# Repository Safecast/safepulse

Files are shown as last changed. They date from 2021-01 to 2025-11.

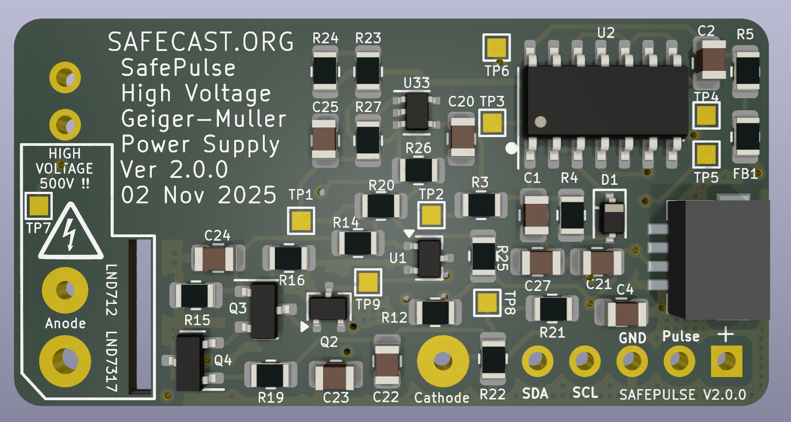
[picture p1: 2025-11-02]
SafePulse_back.jpg

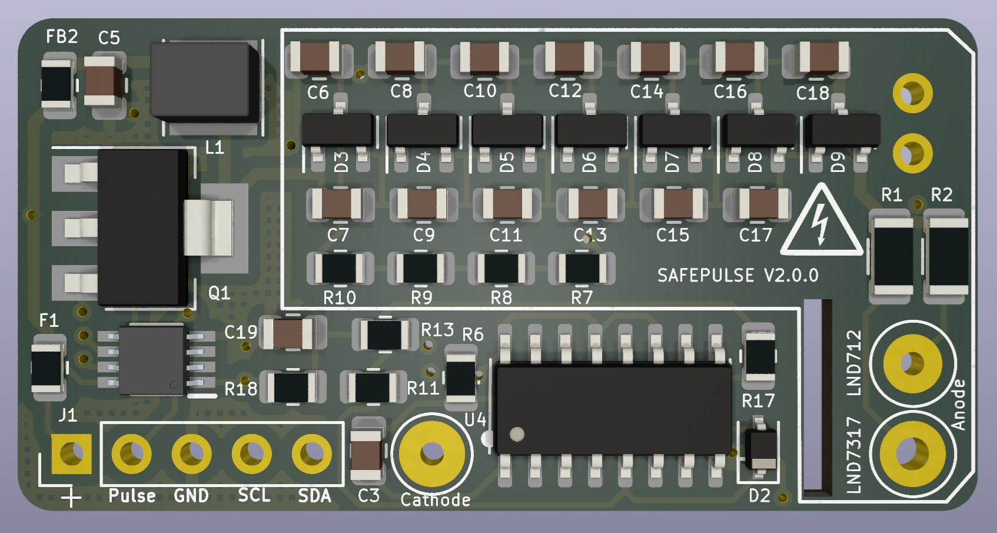
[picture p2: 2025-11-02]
SafePulse_front.jpg

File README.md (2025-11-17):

# SafePulse

An open-source high-voltage power supply (HVPS) and pulse counter designed for Geiger tubes. The Safepulse is utilized in the newest version of Safecast devices, the [bGeigieZen](https://bgeigiezen.safecast.jp) and can be bough directly at [https://bgeigiezen.safecast.jp/store-2/safepulse/](https://bgeigiezen.safecast.jp/store-2/safepulse/)

Safepulse V1 2 5
---

## Table of Contents

- [Overview](#overview)
- [History](#history)
- [Features](#features)
- [Getting Started](#getting-started)
  - [Prerequisites](#prerequisites)
  - [Installation](#installation)
- [Documentation](#documentation)
- [Contributing](#contributing)
- [Issues and Support](#issues-and-support)
- [License](#license)

---

## Overview

SafePulse is a project aimed at creating a fully open-source high-voltage power supply that is compact, efficient, and reliable. Designed specifically for Geiger counters, it facilitates accurate radiation detection and measurement.

---

## History

The SafePulse journey began with Safecast's need for a high-performance HVPS that exceeded existing market solutions. Dan Sythe of International Medcom played a pivotal role in guiding the development process, providing components like the iRover—a commercial-grade miniature HVPS recognized by the IAEA.

While the iRover set a benchmark for reliability and performance, SafePulse was developed to customize its needs to the varying requirements of numerous Safecast device types. Using an open-source design based on a HEX CMOS inverter oscillator, MOSFET switch, and Cockroft-Walton multiplier, the initial design achieved low power consumption (80 µA). However, challenges such as double pulses to the CPU and high count rate predictability led to refinements, including adding a multivibrator for fixed pulse widths. SafePulse is as much a reference design as a specific product, as variants of the core SafePulse design already feature a high-speed nano-amp I2C counter as well as alternative packagings.

SafePulse evolved into a compact 4-layer design to meet size constraints while ensuring consistent performance across component substitutions.

---

## Features

- **Open-Source Design**: All design files and source code are publicly available for modification.
- **High Performance**: Provides reliable high-voltage output tailored for Geiger tubes.
- **Compact and Efficient**: Space-saving design with minimal power consumption.

---

## Getting Started

### Prerequisites

To work with SafePulse, ensure you have the following tools and components:

- [KiCad](https://www.kicad.org/): Open-source electronic design automation software.
- Electronic components listed in the project's bill of materials (BOM).

### Installation

1. **Clone the Repository**:
```

git clone https://github.com/Safecast/safepulse.git

```

2. **Open with KiCad**:
- Launch KiCad.
- Open the `SafePulse.kicad_pro` project file from the cloned repository.

3. **Review and Modify**:
- Access schematics and PCB layouts.
- Make desired modifications or improvements.

---

## Documentation

Detailed schematics and design documents are available in the repository. Refer to the [SafePulse.pdf](https://github.com/Safecast/safepulse/blob/main/SafePulse.pdf) file for comprehensive information.

---

## Contributing

Contributions are welcome! Follow these steps:

1. Fork the repository.
2. Create a new branch for your feature or bug fix:
```

git checkout -b feature-name

```
3. Commit your changes:
```

git commit -m "Add feature"

```
4. Push to your forked repository:
```

git push origin feature-name

```
5. Submit a pull request detailing your changes.

Please ensure contributions align with project objectives and coding standards.

---

## Issues and Support

For issues or questions, visit the [GitHub Issues](https://github.com/Safecast/safepulse/issues) section of the repository.

---

## License

This project is licensed under the MIT License. You are free to use, modify, and distribute this software under its terms.
```

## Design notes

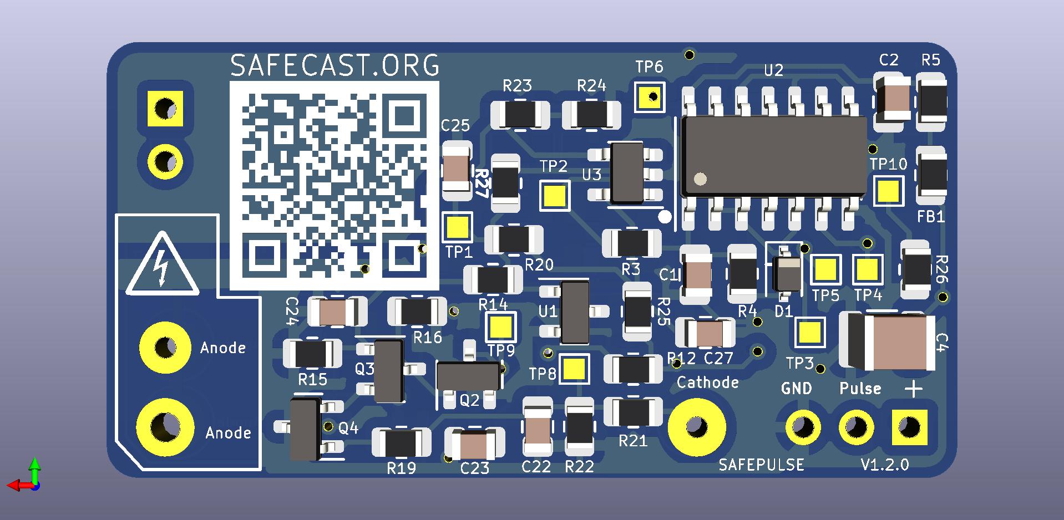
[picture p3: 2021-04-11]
Kicad files/OpenHVPS-5/OpenHVPS-5 front.jpg

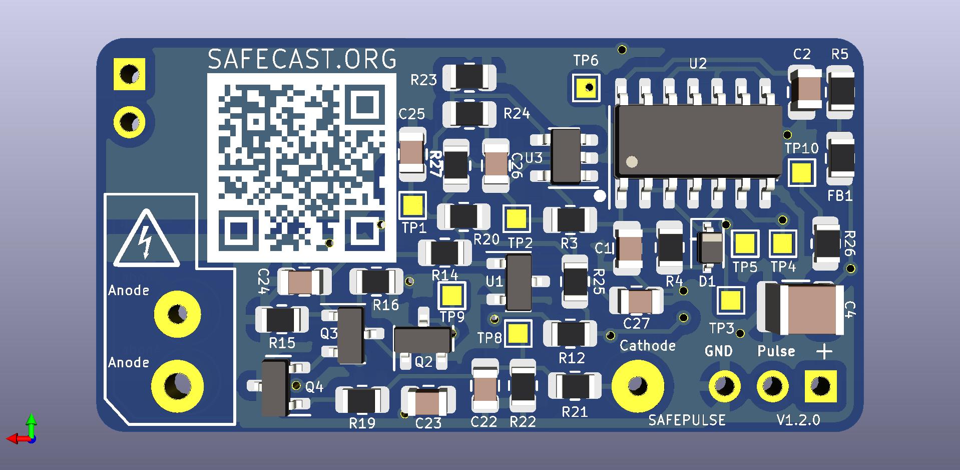
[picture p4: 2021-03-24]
Kicad files/OpenHVPS-5/OpenHVPS-5 font.jpg

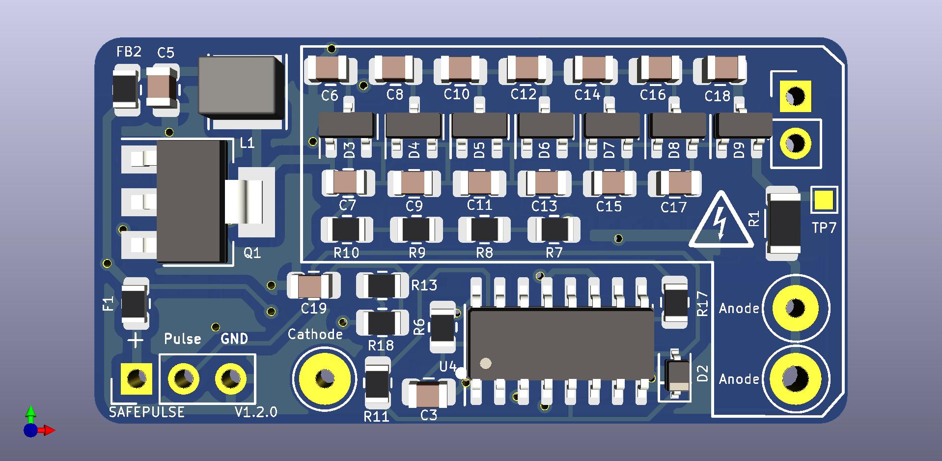
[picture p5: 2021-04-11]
Kicad files/OpenHVPS-5/OpenHVPS-5 back.jpg

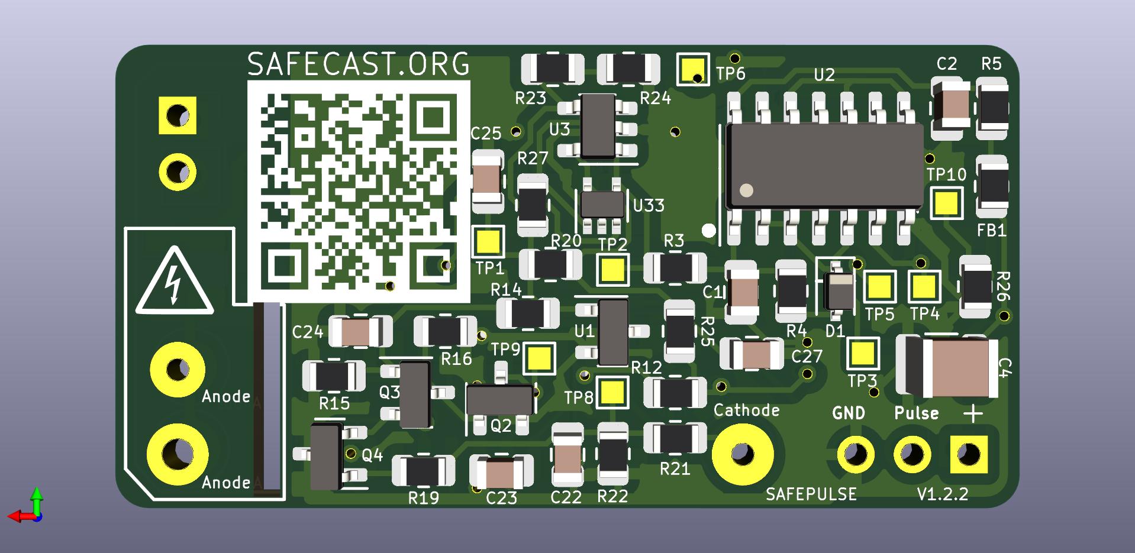
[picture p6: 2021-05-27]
Kicad files/OpenHVPS-5/SafePulse_front.jpg

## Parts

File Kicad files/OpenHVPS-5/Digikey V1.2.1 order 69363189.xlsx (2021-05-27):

# | QUANTITY | PART NUMBER | MANUFACTURER PART NUMBER | DESCRIPTION | CUSTOMER REFERENCE | BACKORDER | UNIT PRICE | EXTENDED PRICE
1 | 10 | 497-15222-1-ND | TS4061AILT-1.25 | IC VREF SHUNT 0.1% SOT23-3 | U1 | 0 | 97.9 | 979
2 | 10 | 296-26814-1-ND | TLV27L1IDBVT | IC OPAMP GP 1 CIRCUIT SOT23-5 | U3 | 10 | 178.7 | 1787
3 | 10 | MAX9910EXK+TCT-ND | MAX9910EXK+T | IC OPAMP GP 1 CIRCUIT SC70-5 | U33 | 0 | 122.6 | 1226
4 | 10 | RHM10.0MAICT-ND | KTR18EZPF1005 | RES SMD 10M OHM 1% 1/4W 1206 | R1 | 0 | 20.9 | 209
5 | 10 | 311-1.54MCRCT-ND | RC0805FR-071M54L | RES SMD 1.54M OHM 1% 1/8W 0805 | R27 | 0 | 5 | 50
6 | 10 | A129767CT-ND | CRGCQ0805F33K | CRGCQ 0805 33K 1% | R24 | 0 | 5.7 | 57
7 | 10 | 311-118KCRCT-ND | RC0805FR-07118KL | RES SMD 118K OHM 1% 1/8W 0805 | R20 | 0 | 5 | 50
8 | 5 | 40626-ND | 40626 | FUSE CLIP CARTRIDGE IN LINE |  | 0 | 27 | 135
9 | 6 | 399-15438-1-ND | C0805C111J5GAC7800 | CAP CER 110PF 50V NP0 0805 |  | 0 | 35 | 210
10 | 6 | 399-15439-1-ND | C0805C121J2GAC7800 | CAP CER 120PF 200V NP0 0805 |  | 0 | 41 | 246
11 | 6 | 399-15446-1-ND | C0805C131J5GAC7800 | CAP CER 130PF 50V NP0 0805 |  | 0 | 39 | 234
12 | 6 | 399-15456-1-ND | C0805C161J1GAC7800 | CAP CER 160PF 100V NP0 0805 |  | 0 | 45 | 270
13 | 6 | 399-16586-1-ND | C0805C181J5HACAUTO | CAP CER 0805 180PF 50V ULTRA STA |  | 0 | 19 | 114
14 | 6 | 490-10741-1-ND | GRM2165C1H201JA01D | CAP CER 200PF 50V C0G/NP0 0805 |  | 0 | 21 | 126
15 | 6 | RR12P20.0KDCT-ND | RR1220P-203-D | RES SMD 20K OHM 0.5% 1/10W 0805 |  | 0 | 12 | 72
16 | 6 | RHM21KAHCT-ND | KTR10EZPF2102 | RES SMD 21K OHM 1% 1/8W 0805 |  | 0 | 21 | 126
17 | 6 | 1712-CPF-A-0805B25KECT-ND | CPF-A-0805B25KE | RES SMD 25K OHM 0.1% 1/10W 0805 |  | 0 | 61 | 366
18 | 6 | P28.7KCCT-ND | ERJ-6ENF2872V | RES SMD 28.7K OHM 1% 1/8W 0805 |  | 0 | 12 | 72
19 | 6 | 541-RCS080530K0FKEACT-ND | RCS080530K0FKEA | RES SMD 30K OHM 1% 0.4W 0805 |  | 0 | 31 | 186
20 | 6 | P32.4KCCT-ND | ERJ-6ENF3242V | RES SMD 32.4K OHM 1% 1/8W 0805 |  | 0 | 12 | 72
21 | 6 | CR0805-FX-3322ELFCT-ND | CR0805-FX-3322ELF | RES SMD 33.2K OHM 1% 1/8W 0805 |  | 0 | 12 | 72
22 | 6 | 13-RT0805BRD0733K6LCT-ND | RT0805BRD0733K6L | RES 33.6K OHM 0.1% 1/8W 0805 |  | 0 | 43 | 258
23 | 6 | RHM34.8KAHCT-ND | KTR10EZPF3482 | RES SMD 34.8K OHM 1% 1/8W 0805 |  | 0 | 21 | 126
24 | 6 | RR12P35.7KDCT-ND | RR1220P-3572-D-M | RES SMD 35.7KOHM 0.5% 1/10W 0805 |  | 0 | 12 | 72
25 | 6 | P39.0KCCT-ND | ERJ-6ENF3902V | RES SMD 39K OHM 1% 1/8W 0805 |  | 0 | 12 | 72
26 | 10 | 1276-1014-1-ND | CL21C101JBANNNC | CAP CER 100PF 50V C0G/NP0 0805 |  | 0 | 6.3 | 63
27 | 10 | YAG3712CT-ND | AC0805FR-0722KL | RES SMD 22K OHM 1% 1/8W 0805 |  | 0 | 5.9 | 59
28 | 10 | 541-CRCW080524K0FKEACCT-ND | CRCW080524K0FKEAC | RES 24K OHM 1% 1/8W 0805 |  | 0 | 7.4 | 74
29 | 10 | 118-CR0805-FX-2702ELFCT-ND | CR0805-FX-2702ELF | RES SMD 27K OHM 1% 1/8W 0805 |  | 0 | 5.9 | 59
30 | 10 | RMCF0805FT28K0CT-ND | RMCF0805FT28K0 | RES 28K OHM 1% 1/8W 0805 |  | 0 | 3.2 | 32
31 | 10 | 2019-RK73H2ATTD2942FCT-ND | RK73H2ATTD2942F | RES 29.4K OHM 1% 1/4W 0805 |  | 0 | 4.1 | 41
32 | 10 | 541-30.9KCCT-ND | CRCW080530K9FKEA | RES SMD 30.9K OHM 1% 1/8W 0805 |  | 0 | 7.7 | 77
33 | 10 | 2019-RK73H2ATTD3162FCT-ND | RK73H2ATTD3162F | RES 31.6K OHM 1% 1/4W 0805 |  | 0 | 4.1 | 41
34 | 10 | RHM34KCHCT-ND | MCR10ERTF3402 | RES SMD 34K OHM 1% 1/8W 0805 |  | 0 | 2 | 20
35 | 10 | 541-36.0KCCT-ND | CRCW080536K0FKEA | RES SMD 36K OHM 1% 1/8W 0805 |  | 0 | 7.7 | 77
36 | 10 | 738-RMCF0805FT36K5CT-ND | RMCF0805FT36K5 | RES 36.5K OHM 1% 1/8W 0805 |  | 0 | 3.2 | 32
37 | 10 | 311-37.4KCRCT-ND | RC0805FR-0737K4L | RES SMD 37.4K OHM 1% 1/8W 0805 |  | 0 | 5 | 50
38 | 6 | 311-38.3KCRCT-ND | RC0805FR-0738K3L | RES SMD 38.3K OHM 1% 1/8W 0805 |  | 0 | 12 | 72
39 | 10 | RMCF0805FT39K2CT-ND | RMCF0805FT39K2 | RES 39.2K OHM 1% 1/8W 0805 |  | 0 | 3.2 | 32
40 | 10 | 541-CRCW080540K0FKEACT-ND | CRCW080540K0FKEA | RES SMD 40K OHM 1% 1/8W 0805 |  | 0 | 7.7 | 77

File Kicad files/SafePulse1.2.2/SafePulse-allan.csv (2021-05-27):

Item | Qty | Reference(s) | Value | LibPart | Digikey
1 | 1 | C1 | 150pF | Device:C | 732-12190-1-ND
2 | 5 | C2, C5, C19, C23, C27 | 10uF | Device:C | 1276-6455-1-ND
3 | 1 | C3 | 1nF | Device:C | 478-1371-1-ND
4 | 1 | C4 | 47uF | Device:C | 587-5425-1-ND
5 | 13 | C6, C7, C8, C9, C10, C11, C12, C13, C14, C15, C16, C17, C18 | 0.1uF | Device:C | 445-6808-1-ND
6 | 1 | C22 | 390pF | Device:C | 399-1132-1-ND
7 | 2 | C24, C25 | 10nF | Device:C | 1276-1015-1-ND
8 | 2 | D1, D2 | BAS16J | Diode:1N4148W | 1727-4797-1-ND
9 | 7 | D3, D4, D5, D6, D7, D8, D9 | BAV23S | Diode:BAV99 | BAV23SFSCT-ND
10 | 1 | F1 | Polyfuse | Device:Polyfuse_Small | 490-8510-1-ND
11 | 2 | FB1, FB2 | 74279220321 | Device:Ferrite_Bead | 732-6125-1-ND
15 | 1 | L1 | 4.7uH | 2021-01-06_02-33-04:NRS6020T2R2NMGJ | 587-4451-1-ND
16 | 1 | Q1 | FQT7N10L | Transistor_FET:IRF6655 | FQT7N10LTFCT-ND
17 | 1 | Q2 | BC846A | Transistor_BJT:BC846 | BC846A-7FDICT-ND
18 | 2 | Q3, Q4 | MMBT3906 | Transistor_BJT:MMBT3906 | MMBT3906LT1GOSCT-ND
19 | 1 | R1 | 4.99M | Device:R | RHM4.99MAICT-ND
20 | 1 | R3 | 100K | Device:R | RMCF0805FT100KCT-ND
21 | 1 | R4 | 10K | Device:R | RNCP0805FTD10K0CT-ND
22 | 3 | R5, R12, R25 | 100 | Device:R | A106053CT-ND
23 | 1 | R6 | 121k | Device:R | 2019-RK73H2ATTD1213FCT-ND
24 | 4 | R7, R8, R9, R10 | 22M | Device:R | RMCF0805FT22M0CT-ND
25 | 1 | R11 | 33k | Device:R | A129767CT-ND
26 | 2 | R13, R19 | 100k | Device:R | RMCF0805FT100KCT-ND
27 | 1 | R14 | 357k | Device:R | 2019-RK73H2ATTD3573FCT-ND
28 | 1 | R15 | 220k | Device:R | CR0805-FX-2203ELFCT-ND
29 | 1 | R16 | 1M | Device:R | YAG3361CT-ND
30 | 1 | R17 | 499k | Device:R | RMCF0805FT499KCT-ND
31 | 1 | R18 | 1k | Device:R | RNCP0805FTD1K00CT-ND
32 | 1 | R20 | 118K | Device:R | 311-118KCRCT-ND
33 | 1 | R21 | 47k | Device:R | 311-47.0KCRCT-ND
34 | 1 | R22 | 20k | Device:R | RMCF0805FT20K0CT-ND
35 | 2 | R23, R27 | 1.54M | Device:R | 311-1.54MCRCT-ND
36 | 1 | R24 | 22k | Device:R | CR0805-FX-2202ELFCT-ND
37 | 1 | R26 | 0.1E | Device:R | 408-1556-1-ND
40 | 1 | U2 | 74HC14 | 74xx:74HC14 | 296-9179-1-ND
41 | 1 | U3 | MAX9910EXK+T | Amplifier_Operational:MCP6L01Ux-xOT | MAX9910EXK+TCT-ND
42 | 1 | U4 | CD14538BM | 4xxx:4538 | 296-32849-5-ND
43 | 1 | Fuse Holder |  |  | 40626-ND

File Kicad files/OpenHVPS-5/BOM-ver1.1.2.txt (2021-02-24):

qty Digikey number

resistors
1  408-1556-1-ND
3  A106053CT-ND
1  YAG1240CT-ND
1  RNCP0805FTD10K0CT-ND
1  P20.0KCCT-ND
1  A129767CT-ND
1  311-47.0KCRCT-ND
2  RMCF0805FT100KCT-ND
1  2019-RK73H2ATTD1213FCT-ND
1  311-392KCRCT-ND
1  A126370CT-ND
1  RMCF0805FT499KCT-ND
1  YAG3361CT-ND
1  541-1.50MCCT-ND
1  311-3.16MCRCT-ND
1  RHM4.7MAICT-ND
5  RMCF0805FT22M0CT-ND

caps
1  732-12190-1-ND
1  1276-1261-1-ND
1  1276-1303-1-ND
2  478-1371-1-ND
1  1276-1015-1-ND
1  587-5425-1-ND
13 445-C2012X7T2E104K125AACT-ND
5  1276-6455-1-ND

semiconductors
2  1727-4797-1-ND
7  BAV23SFSCT-ND
1  BC846A-7FDICT-ND
2  MMBT3906LT1GOSCT-ND
1  FQT7N10LTFCT-ND
1  296-9179-1-ND
1  296-32849-5-ND
1  MAX4162EUK+TCT-ND
1  MAX6008AEUR+TCT-ND

Inductors
1  587-4451-1-ND
2  445-172907-1-ND

extra parts for 1.25V reference
1  MAX6006AEUR+TCT-ND
1   P357KDACT-ND
1  311-1.54MCRCT-ND

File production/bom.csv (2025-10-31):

Designator | Footprint | Quantity | Value | LCSC Part #
C1 | 0805 | 1 | 110pF | C17694684
C10, C11, C12, C13, C14, C15, C16, C17, C18, C21, C6, C7, C8, C9 | 0805 | 14 | 0.1uF | C710458
C19, C2, C23, C27, C5 | 0805 | 5 | 10uF | C1713
C20 | 0805 | 1 | 100pF | C62768
C22 | 0805 | 1 | 390pF | C1741
C24 | 0805 | 1 | 10nF | C97905
C25 | 0805 | 1 | 2.2uF | C19110
C3 | 0805 | 1 | 1nF | C94121
C4 | 0805 | 1 | 47uF | C76636
D1, D2 | D_SOD-323 | 2 | BAS16J | C282360
D3, D4, D5, D6, D7, D8, D9 | SOT-23 | 7 | BAV23S | C151049
F1 | 0805 | 1 | Polyfuse | C20978
FB1, FB2 | 0805 | 2 | 74279220321 | C515370
IC1 | SOP65P400X80-8N | 1 | S-35770E01I-K8T2U
J2 | 4208 | 1 | JST SM04B-SRSS-TB(LF)(SN) | C160404
L1 | L_Taiyo-Yuden_MD-4040 | 1 | 4.7uH | C5289366
Q1 | SOT-223-3_TabPin4 | 1 | FQT7N10L | C154506
Q2 | SOT-323_SC-70 | 1 | BC846A | C507907
Q3, Q4 | SOT-23 | 2 | MMBT3906 | C53444
R1 | 1206 | 1 | 4.99M | C488845
R10, R26, R7, R8, R9 | 0805 | 5 | 22M | C34719
R11 | 0805 | 1 | 33k | C17633
R12, R25, R5 | 0805 | 3 | 100 | C328380
R13, R19, R3 | 0805 | 3 | 100k | C96346
R14 | 0805 | 1 | 357k | C865422
R15 | 0805 | 1 | 220k | C104108
R16 | 0805 | 1 | 1M | C107700
R17 | 0805 | 1 | 499k | C17721
R18 | 0805 | 1 | 1k | C95781
R2 | 1206 | 1 | 10M | C275643
R20 | 0805 | 1 | 118K | C2999465
R21 | 0805 | 1 | 47k | C328397
R22 | 0805 | 1 | 20K | C2988970
R23, R27 | 0805 | 2 | 1.54M | C422787
R24 | 0805 | 1 | 33k | C17633
R4 | 0805 | 1 | 10K | C17414
R6 | 0805 | 1 | 121k | C17438
U1 | SOT-323_SC-70 | 1 | TS4061AICT-1.25 | C5267733
U2 | SOIC-14_3.9x8.7mm_P1.27mm | 1 | 74HC14 | C232776
U33 | SOT-353_SC-70-5 | 1 | MAX9910EXK+T | C2057992
U4 | SOIC-16_3.9x9.9mm_P1.27mm | 1 | CD14538BM | C56163

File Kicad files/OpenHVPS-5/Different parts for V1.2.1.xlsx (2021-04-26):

Item | Qty | Reference(s) | Value | LibPart | Footprint | Datasheet | Digikey
38 | 1 | U1 | TS4061AILT-1.25 | Reference_Voltage:MAX6035xxUR30 | Package_TO_SOT_SMD:SOT-23 | https://www.st.com/content/ccc/resource/technical/document/datasheet/99/0a/06/84/6d/21/40/45/DM00114435.pdf/files/DM00114435.pdf/jcr:content/translations/en.D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 | 497-15222-1-ND
40 | 1 | U3 | TLV27L1IDBVT | Amplifier_Operational:TLV2371DBV | Package_TO_SOT_SMD:SOT-23-5 | https://www.ti.com/lit/ds/slos378b/slos378b.pdf | 296-26814-1-ND
42 | 1 | U33 | MAX9910EXK+T | Amplifier_Operational:MCP6L01Ux-xOT | Package_TO_SOT_SMD:SOT-353_SC-70-5 | https://datasheets.maximintegrated.com/en/ds/MAX9910-MAX9913.pdf | MAX9910EXK+TCT-ND

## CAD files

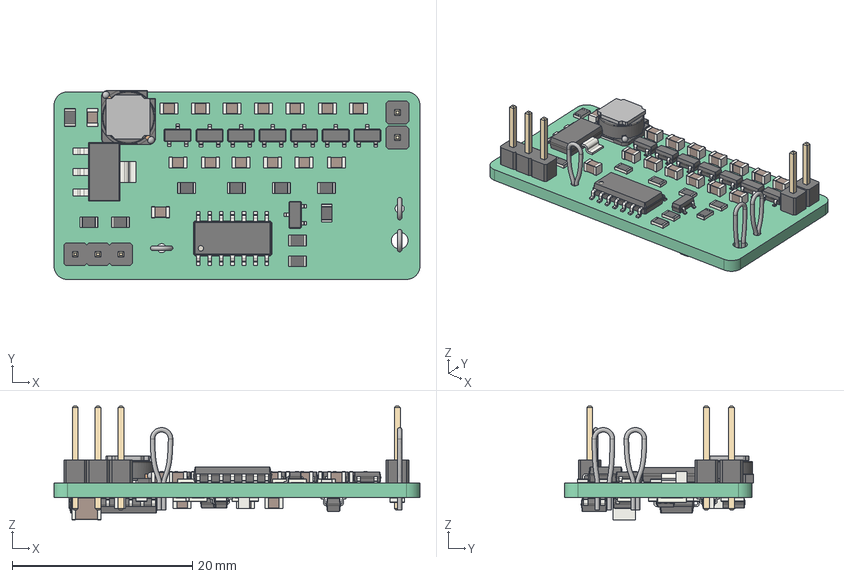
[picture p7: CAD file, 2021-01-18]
Kicad files/OpenHVPS-3/OpenHVPS_ray1.step
40.6 x 21.0 x 12.6 mm
Local_CS_9fd0
Pcb_9fd0 x 2
"C11"_C_0805_2012Metric_0ded1baa-ca0f-4eb8-9fe3-abc3e55363c0 x 63
"H2"_TestPoint_Loop_D2.50mm_Drill1.0mm_ 11ed5dd0-3845-4ec0-aff6-0cf91cf9e4f5 x 6
"D8"_SOT_23_1b05ef8d-8421-4177-840e-f2ee5bb1c449 x 27
"H2"_TestPoint_Loop_D2.50mm_Drill1.85mm_ 1ebf93a8-27ba-4b17-8096-7d5680e3ab7a x 3
"R8"_R_0805_2012Metric_37b83e8e-4dd7-45b5-b7a4-df7b3f7e630d x 69
"D1"_D_SOT_23_486a33f8-06b4-4b62-b7df-41ee1187ac09 x 6
REF_PinHeader_1x01_P254mm_Vertical_ 87bfeb40-7740-40c1-a5ee-991e0e19abb2 x 6
"L1"_User_Library-SMDpowerInductor_ 8efecfac-bf67-4a0d-b4e2-4423f34b4e95[2] x 3
"L1"_Fillet003_fd_sp_8efecfac-bf67-4a0d-b4e2-4423f34b4e95[3] x 3
"U2"_SOIC_14_39x87mm_P127mm_9bc91ab9-ea0d-4d49-869c-6cbfd59bc71c x 3
"J2"_PinHeader_1x03_P254mm_Vertical_ 9c64ad49-6b74-4c8f-b637-c488a6158a7a x 3
"Q1"_SOT_223_c51ee79e-3f73-43b1-a02b-215e7cb4282f x 3
"Q3"_SOT_363_SC_70_6_23e69448-3871-482e-98a8-997065de55e0 x 3
"U3"_SOT_23_5_4d49d867-5260-41aa-9fdb-ece142794780 x 3
"R1"_R_1206_3216Metric_70a92563-8c18-463e-b65b-e07993cc5b64 x 3
"U4"_SOIC_16_39x99mm_P127mm_c50f467c-c713-4f3a-a5a9-49f5d52d5fa9 x 3
"C4"_C_1210_3225Metric_e83b62ee-5154-494f-978e-5abf8272b843 x 3

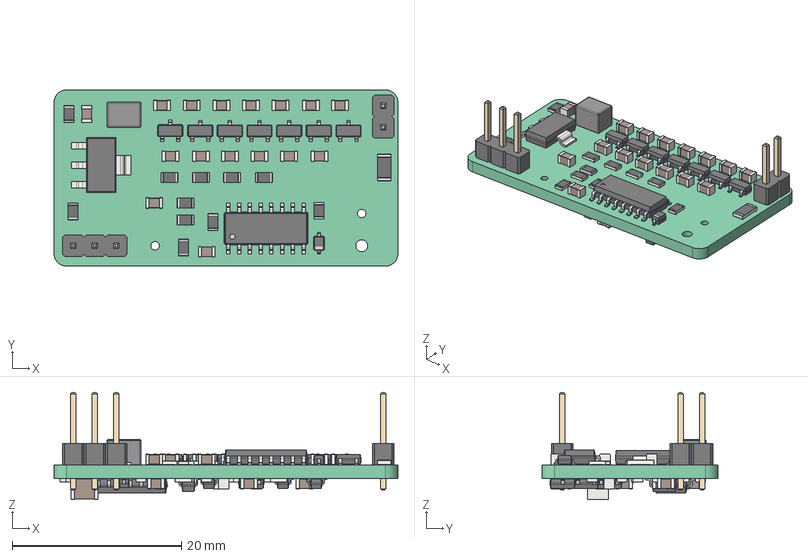
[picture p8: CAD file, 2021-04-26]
Kicad files/OpenHVPS-5/OpenHVPS -5.step
40.6 x 20.8 x 12.6 mm
Pcb_10e8 x 2
F1_R_0805_2012Metric_b9191f89bbf2 x 84
two_pinheader1_PinHeader_1x02_P254mm_Vertical_006439a5dde2 x 3
C10_C_0805_2012Metric_abc3e55363c0 x 72
D8_SOT_23_f2ee5bb1c449 x 33
J1_PinHeader_1x03_P254mm_Vertical_f24be82ae70c x 3
R1_R_1206_3216Metric_e07993cc5b64 x 3
L1_L_Wuerth_MAPI_4030_4423f34b4e95[2] x 3
U4_SOIC_16_39x99mm_P127mm_49f5d52d5fa9 x 3
Q1_SOT_223_215e7cb4282f x 3
D2_D_SOD_323_1f0c94ab2243 x 6
U3_SOT_23_5_ece142794780 x 3
U2_SOIC_14_39x87mm_P127mm_6cbfd59bc71c x 3
C4_C_1210_3225Metric_5abf8272b843 x 3

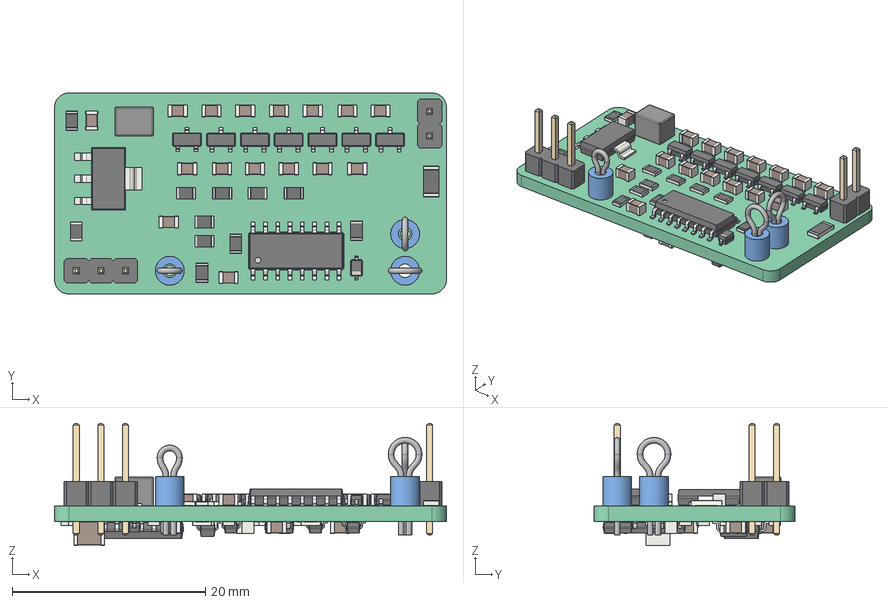
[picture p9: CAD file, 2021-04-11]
Kicad files/OpenHVPS-5/Unnamed.step
40.6 x 20.8 x 12.6 mm
Local_CS_10e8
Pcb_10e8 x 2
F1_R_0805_2012Metric_b9191f89bbf2 x 84
two_pinheader1_PinHeader_1x02_P254mm_Vertical_006439a5dde2 x 3
C10_C_0805_2012Metric_abc3e55363c0 x 72
H2_TestPoint_Loop_D3_50mm_Drill1_4mm_Beaded_cp_0cf91cf9e4f5 x 6
D8_SOT_23_f2ee5bb1c449 x 33
H1_TestPoint_Loop_D2_60mm_Drill1_4mm_Beaded_cp_43681d584878 x 3
J1_PinHeader_1x03_P254mm_Vertical_f24be82ae70c x 3
R1_R_1206_3216Metric_e07993cc5b64 x 3
L1_L_Wuerth_MAPI_4030_4423f34b4e95[2] x 3
U4_SOIC_16_39x99mm_P127mm_49f5d52d5fa9 x 3
Q1_SOT_223_215e7cb4282f x 3
D2_D_SOD_323_1f0c94ab2243 x 6
U3_SOT_23_5_ece142794780 x 3
U2_SOIC_14_39x87mm_P127mm_6cbfd59bc71c x 3
C4_C_1210_3225Metric_5abf8272b843 x 3

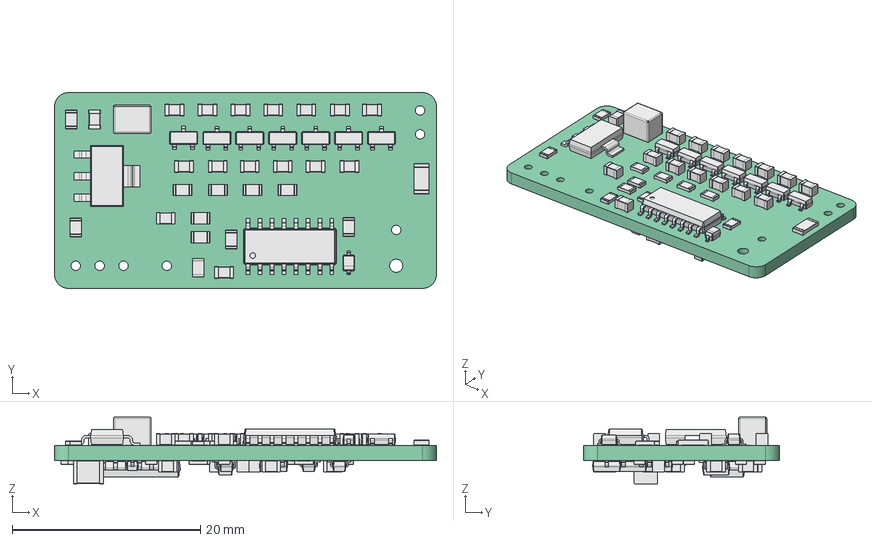
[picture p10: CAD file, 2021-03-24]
Kicad files/OpenHVPS-5/OpenHVPS_5_no_pin_headers.FCStd
40.6 x 20.8 x 7.10 mm
Pcb_10e8
F1_R_0805_2012Metric_b9191f89bbf2 x 27
C10_C_0805_2012Metric_abc3e55363c0 x 24
D8_SOT_23_f2ee5bb1c449 x 11
R1_R_1206_3216Metric_e07993cc5b64
L1_L_Wuerth_MAPI_4030_4423f34b4e95[2]
U4_SOIC_16_39x99mm_P127mm_49f5d52d5fa9
Q1_SOT_223_215e7cb4282f
D2_D_SOD_323_1f0c94ab2243 x 2
U3_SOT_23_5_ece142794780
U2_SOIC_14_39x87mm_P127mm_6cbfd59bc71c
C4_C_1210_3225Metric_5abf8272b843

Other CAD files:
Kicad files/OpenHVPS-5/OpenHVPS-51.step
Kicad files/OpenHVPS-5/OpenHVPS_5_no_pin_headers-OpenHVPS-5.step
Kicad files/OpenHVPS-5/OpenHVPS_5.FCStd
Kicad files/OpenHVPS-5/Unnamed.FCStd

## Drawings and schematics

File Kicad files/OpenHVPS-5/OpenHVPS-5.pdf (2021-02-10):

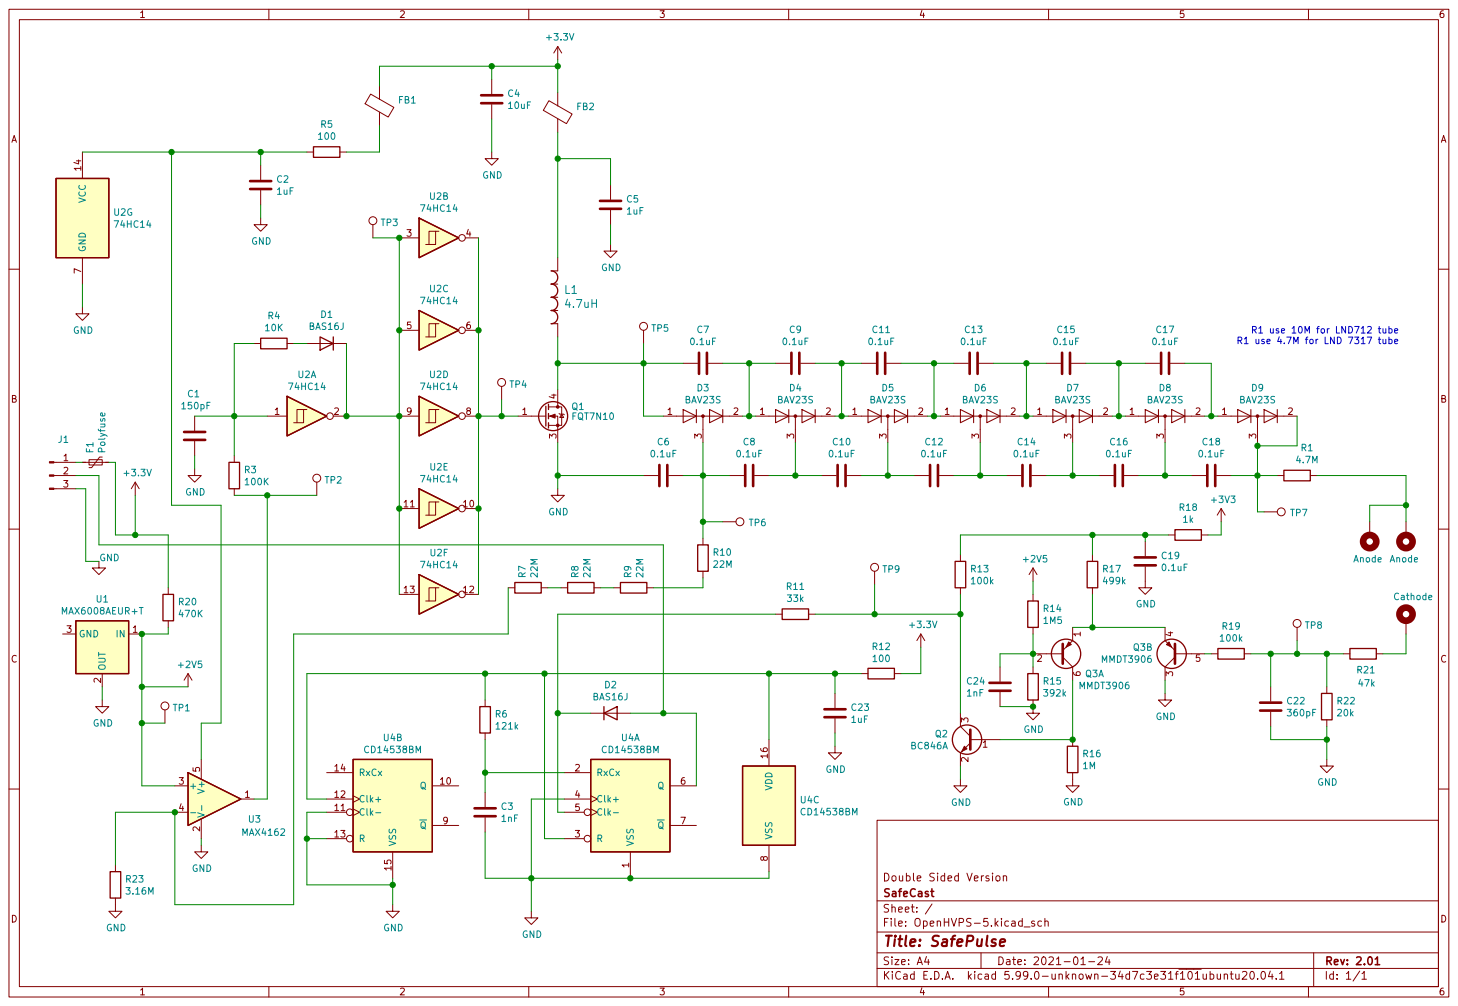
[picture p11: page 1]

File: OpenHVPS-5.kicad_sch Sheet: / SafeCast Double Sided Version GND

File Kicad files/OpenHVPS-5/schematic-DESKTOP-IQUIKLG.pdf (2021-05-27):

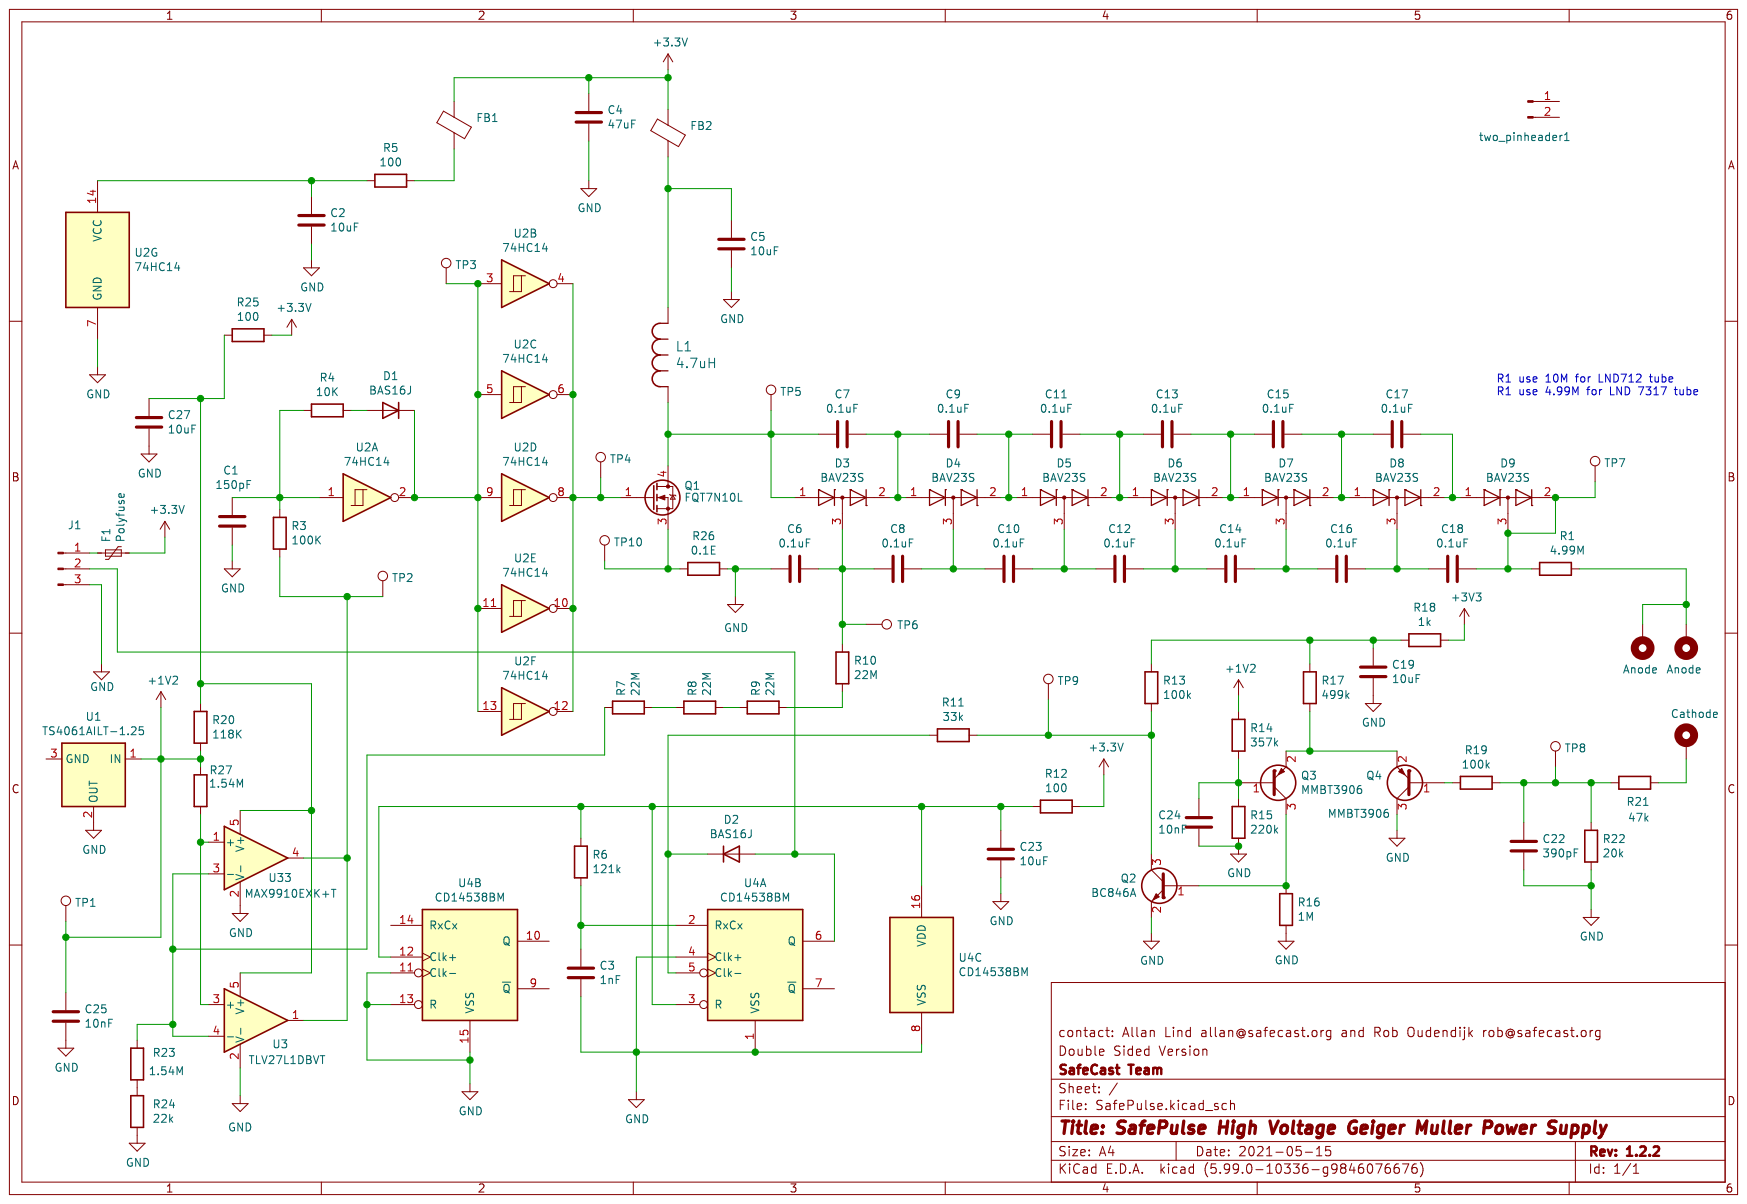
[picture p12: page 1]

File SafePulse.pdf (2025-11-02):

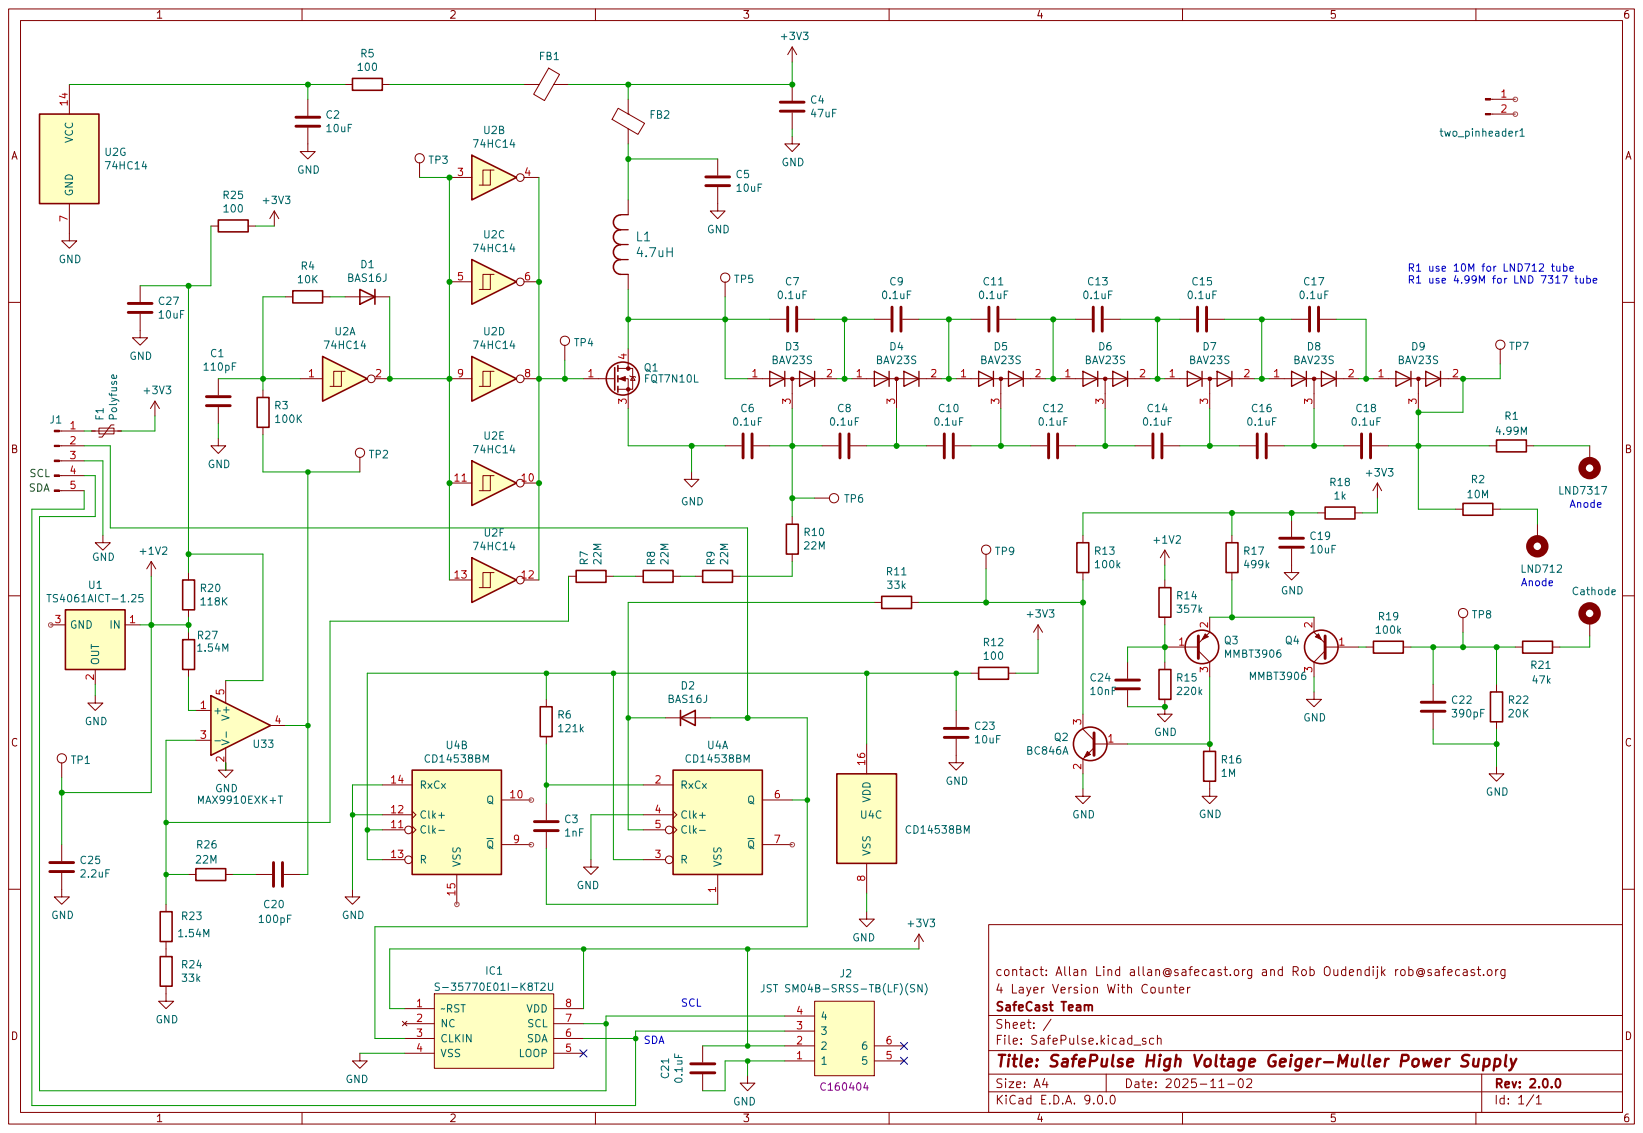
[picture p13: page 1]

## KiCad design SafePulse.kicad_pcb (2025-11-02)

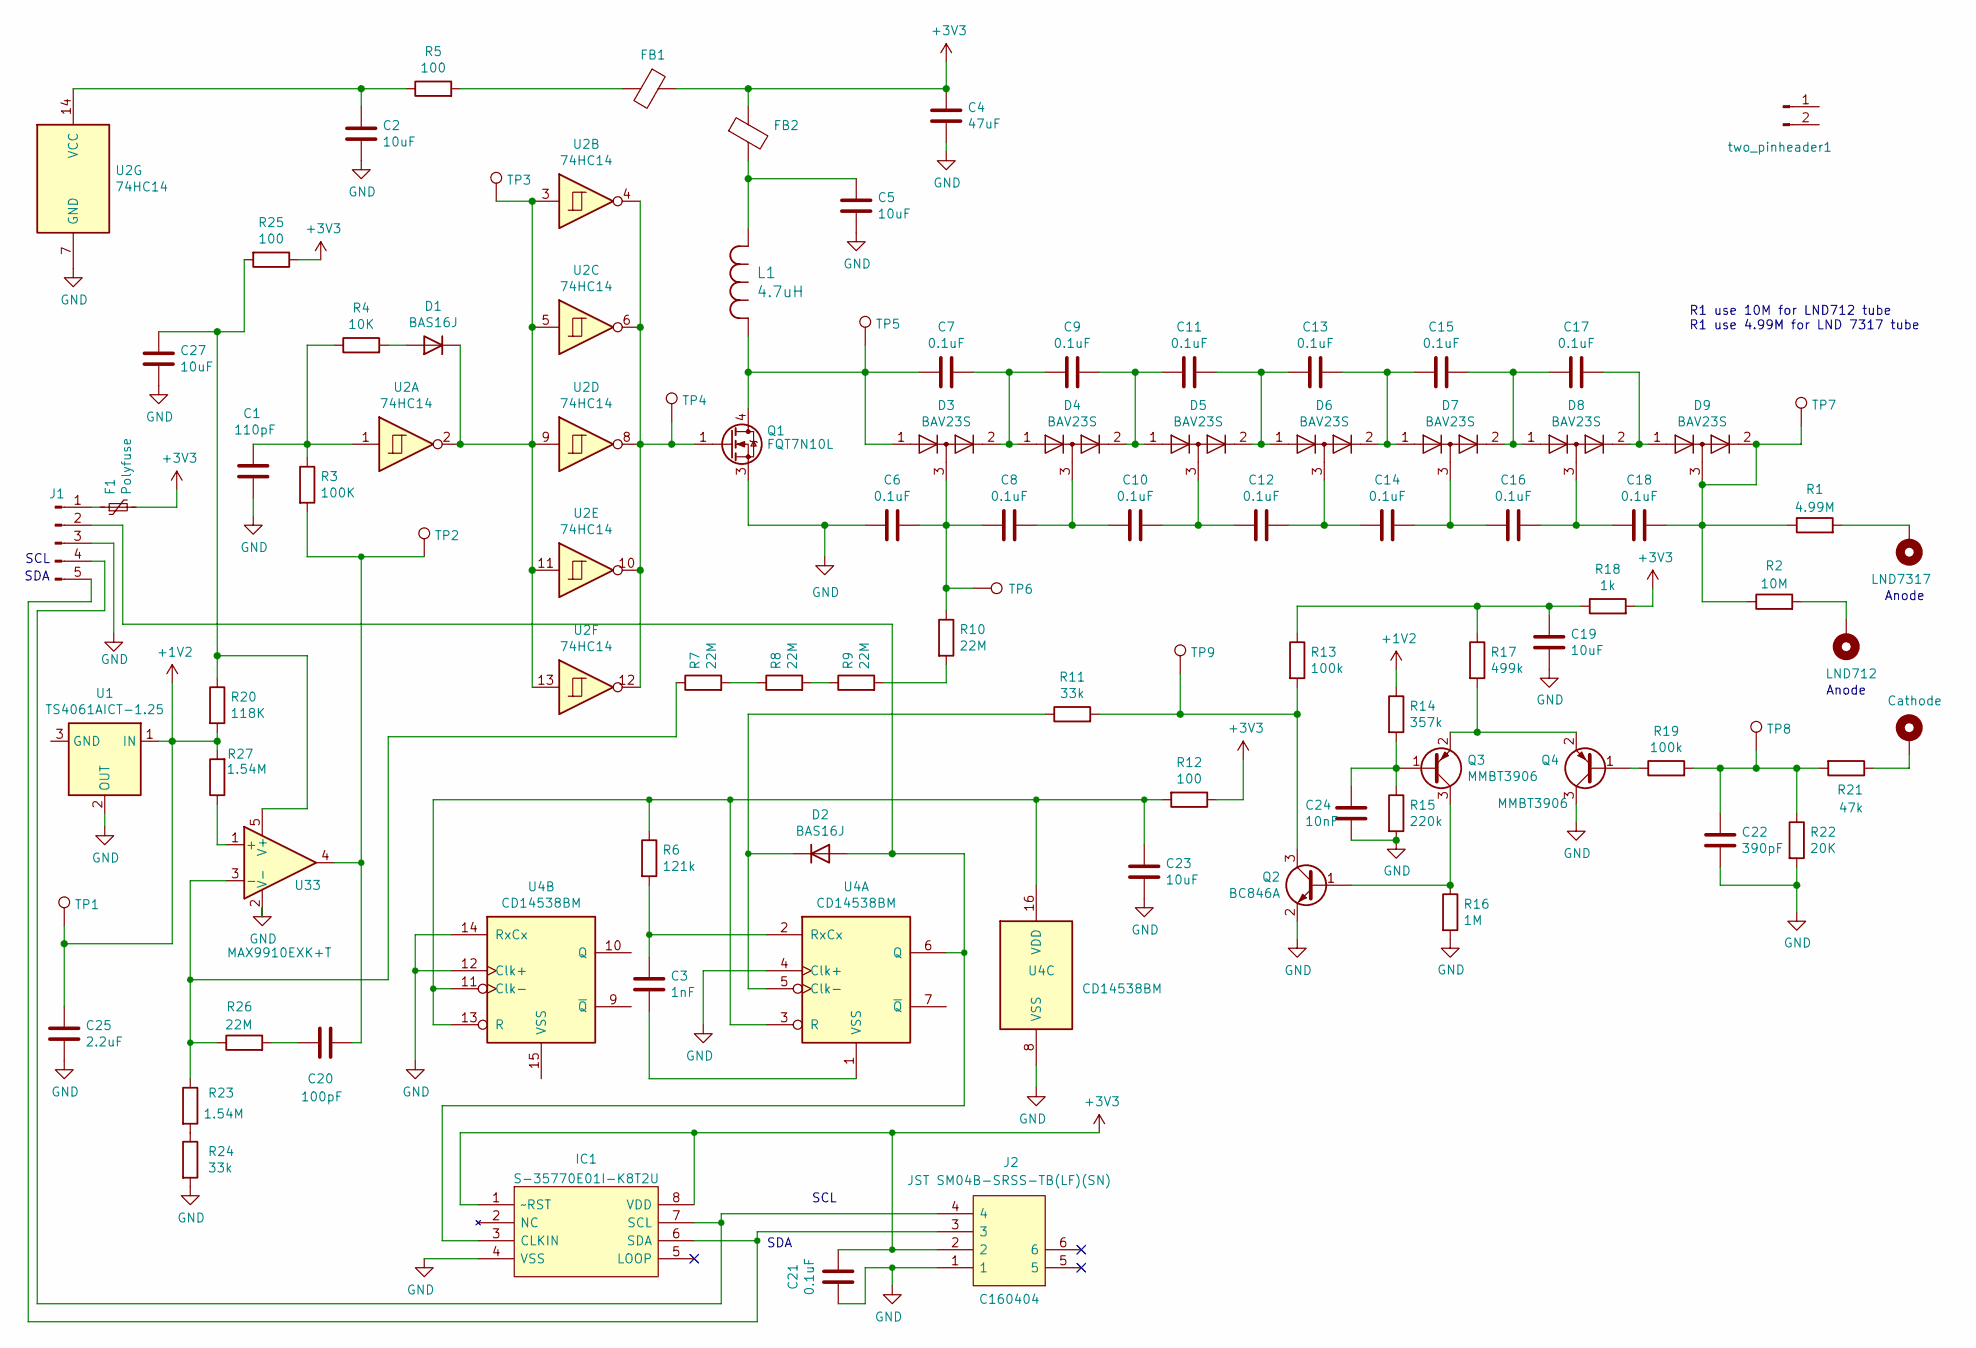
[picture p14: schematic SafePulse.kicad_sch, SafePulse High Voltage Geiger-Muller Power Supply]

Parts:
C1: 110pF; C_0805_2012Metric; Digikey 3372-0805B101K101BDTR-ND
C2, C5, C19, C23, C27: 10uF; C_0805_2012Metric; Digikey 1276-6455-1-ND
C3: 1nF; C_0805_2012Metric; Digikey 478-1371-1-ND
C4: 47uF; C_0805_2012Metric; Digikey 1276-6455-1-ND
C6, C7, C8, C9, C10, C11, C12, C13, C14, C15, C16, C17, C18, C21: 0.1uF; C_0805_2012Metric; Digikey 445-6808-1-ND
C20: 100pF; C_0805_2012Metric; Digikey 3372-0805B101K101BDTR-ND
C22: 390pF; C_0805_2012Metric; Digikey 399-1132-1-ND
C24: 10nF; C_0805_2012Metric; Digikey 1276-1015-1-ND
C25: 2.2uF; C_0805_2012Metric; Digikey 1276-1015-1-ND
D1, D2: BAS16J; D_SOD-323; Digikey 1727-4797-1-ND
D3, D4, D5, D6, D7, D8, D9: BAV23S; SOT-23; Digikey BAV23SFSCT-ND
F1: Polyfuse; R_0805_2012Metric; Digikey 490-8510-1-ND
FB1, FB2: 74279220321; R_0805_2012Metric; Digikey 732-6125-1-ND
H1: Cathode; TestPoint_Loop_D2.60mm_Drill1.4mm_Beaded
H2: LND712; TestPoint_Loop_D3.50mm_Drill1.4mm_Beaded
H4: LND7317; TestPoint_Loop_D3.50mm_Drill1.4mm_Beaded
IC1: S-35770E01I-K8T2U; SOP65P400X80-8N; Manufacturer_Part_Number S-35770E01I-K8T2U; Mouser Part Number 628-S35770E01I-K8T2U
J1: Conn_01x03_Male; PinHeader_1x05_P2.54mm_Vertical
J2: JST SM04B-SRSS-TB(LF)(SN); 4208; Manufacturer_Part_Number 4208; Mouser Part Number 485-4208
L1: 4.7uH; L_Taiyo-Yuden_MD-4040; Digikey 587-4451-1-ND
Q1: FQT7N10L; SOT-223-3_TabPin4; Digikey FQT7N10LTFCT-ND
Q2: BC846A; SOT-323_SC-70; Digikey BC846A-7FDICT-ND
Q3, Q4: MMBT3906; SOT-23; Digikey MMBT3906LT1GOSCT-ND
R1: 4.99M; R_1206_3216Metric; Digikey RHM4.99MAICT-ND
R2: 10M; R_1206_3216Metric; Digikey RHM4.99MAICT-ND
R3: 100K; R_0805_2012Metric; Digikey RMCF0805FT100KCT-ND
R4: 10K; R_0805_2012Metric; Digikey RNCP0805FTD10K0CT-ND
R5: 100; R_0805_2012Metric; LCSC Part # C328380
R6: 121k; R_0805_2012Metric; Digikey 2019-RK73H2ATTD1213FCT-ND
R7, R8, R9, R10, R26: 22M; R_0805_2012Metric; Digikey RMCF0805FT22M0CT-ND
R11, R24: 33k; R_0805_2012Metric; Digikey A129767CT-ND
R12, R25: 100; R_0805_2012Metric; Digikey A106053CT-ND
R13, R19: 100k; R_0805_2012Metric; Digikey RMCF0805FT100KCT-ND
R14: 357k; R_0805_2012Metric; Digikey 2019-RK73H2ATTD3573FCT-ND
R15: 220k; R_0805_2012Metric; Digikey CR0805-FX-2203ELFCT-ND
R16: 1M; R_0805_2012Metric; Digikey YAG3361CT-ND
R17: 499k; R_0805_2012Metric; Digikey RMCF0805FT499KCT-ND
R18: 1k; R_0805_2012Metric; Digikey RNCP0805FTD1K00CT-ND
R20: 118K; R_0805_2012Metric; Digikey 311-118KCRCT-ND
R21: 47k; R_0805_2012Metric; Digikey 311-47.0KCRCT-ND
R22: 20K; R_0805_2012Metric; Digikey RMCF0805FT20K0CT-ND
R23, R27: 1.54M; R_0805_2012Metric; Digikey 311-1.54MCRCT-ND
TP1, TP2, TP3, TP4, TP5, TP6, TP7, TP8, TP9: TestPoint; TestPoint_Pad_1.0x1.0mm
U1: TS4061AICT-1.25; SOT-323_SC-70; Digikey 497-15222-1-ND
U2: 74HC14; SOIC-14_3.9x8.7mm_P1.27mm; LCSC Part # C232776
U4: CD14538BM; SOIC-16_3.9x9.9mm_P1.27mm; Digikey 296-32849-5-ND
U33: MAX9910EXK+T; SOT-353_SC-70-5; Digikey MAX9910EXK+TCT-ND
two_pinheader1: Conn_01x03_Male; PinHeader_1x02_P2.54mm_Vertical

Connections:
+1V2: C25.1, R14.1, R20.2, R27.2, TP1.1, U1.1 (IN)
+3V3: C4.1, C21.2, F1.2, FB1.1, FB2.1, IC1.1 (~RST), IC1.8 (VDD), J2.2, R12.1, R18.2, R25.1
GND: C1.2, C2.2, C4.2, C5.2, C6.1, C19.2, C21.1, C22.2, C23.2, C24.2, C25.2, C27.2, IC1.4 (VSS), J1.3, J2.1, Q1.3 (S), Q2.2 (E), Q4.3 (C), R15.2, R16.2, R22.2, R24.2, U1.2 (OUT), U2.7 (GND), U4.4 (Clk+), U4.8 (VSS), U4.12 (Clk+), U4.14 (RxCx), U33.2 (V-)
unnamed: C1.1, R3.1, R4.1, U2.1
unnamed: C5.1, FB2.2, L1.1
unnamed: C6.2, C8.1, D3.3 (K), R10.1, TP6.1
unnamed: C8.2, C10.1, D4.3 (K)
unnamed: C10.2, C12.1, D5.3 (K)
unnamed: C12.2, C14.1, D6.3 (K)
unnamed: C14.2, C16.1, D7.3 (K)
unnamed: C16.2, C18.1, D8.3 (K)
unnamed: C19.1, R13.1, R17.1, R18.1
unnamed: C20.1, R26.2
unnamed: C20.2, R3.2, TP2.1, U33.4
unnamed: C22.1, R19.2, R21.2, R22.1, TP8.1
unnamed: D1.2 (A), R4.2
unnamed: D1.1 (K), TP3.1, U2.2, U2.3, U2.5, U2.9, U2.11, U2.13
unnamed: D2.2 (A), IC1.3 (CLKIN), J1.2, U4.6 (Q)
unnamed: D2.1 (K), R11.1, U4.5 (Clk-)
unnamed: C7.2, C9.1, D3.2 (A), D4.1 (K)
unnamed: C9.2, C11.1, D4.2 (A), D5.1 (K)
unnamed: C11.2, C13.1, D5.2 (A), D6.1 (K)
unnamed: C13.2, C15.1, D6.2 (A), D7.1 (K)
unnamed: C15.2, C17.1, D7.2 (A), D8.1 (K)
unnamed: C17.2, D8.2 (A), D9.1 (K)
unnamed: C18.2, D9.2 (A), D9.3 (K), R1.1, R2.1, TP7.1
unnamed: FB1.2, R5.2
unnamed: H1.1, R21.1
unnamed: H2.1, R2.2
unnamed: H4.1, R1.2
unnamed: IC1.7 (SCL), J1.4, J2.4
unnamed: IC1.6 (SDA), J1.5, J2.3
unnamed: F1.1, J1.1
unnamed: C7.1, D3.1 (K), L1.2, Q1.4 (D), TP5.1
unnamed: Q1.1 (G), TP4.1, U2.4, U2.6, U2.8, U2.10, U2.12
unnamed: Q2.1 (B), Q3.3 (C), R16.1
unnamed: Q2.3 (C), R11.2, R13.2, TP9.1
unnamed: C24.1, Q3.1 (B), R14.2, R15.1
unnamed: Q3.2 (E), Q4.2 (E), R17.2
unnamed: Q4.1 (B), R19.1
unnamed: R7.2, R8.1
unnamed: R8.2, R9.1
unnamed: R9.2, R10.2
unnamed: R23.2, R24.1
unnamed: C2.1, R5.1, U2.14 (VCC)
unnamed: C23.1, R6.1, R12.2, U4.3 (R), U4.11 (Clk-), U4.13 (R), U4.16 (VDD)
unnamed: C3.1, R6.2, U4.2 (RxCx)
unnamed: C3.2, U4.1 (VSS)
unnamed: R27.1, U33.1 (+)
unnamed: R7.1, R23.1, R26.1, U33.3 (-)
unnamed: C27.1, R20.1, R25.2, U33.5 (V+)

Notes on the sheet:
SCL
SDA
R1 use 10M for LND712 tube R1 use 4.99M for LND 7317 tube
Anode

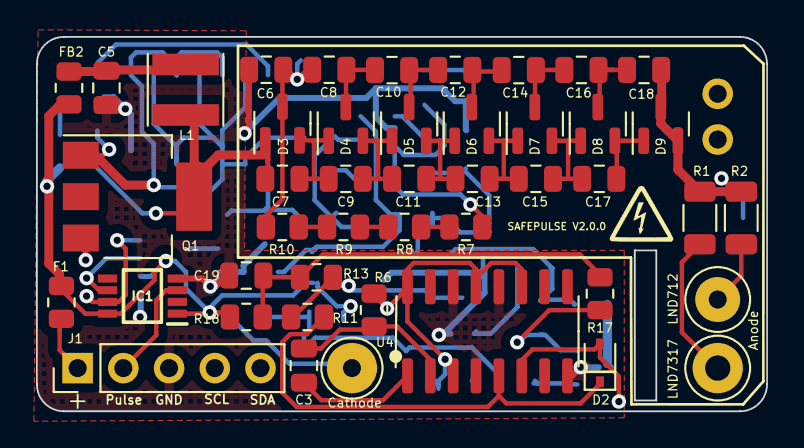
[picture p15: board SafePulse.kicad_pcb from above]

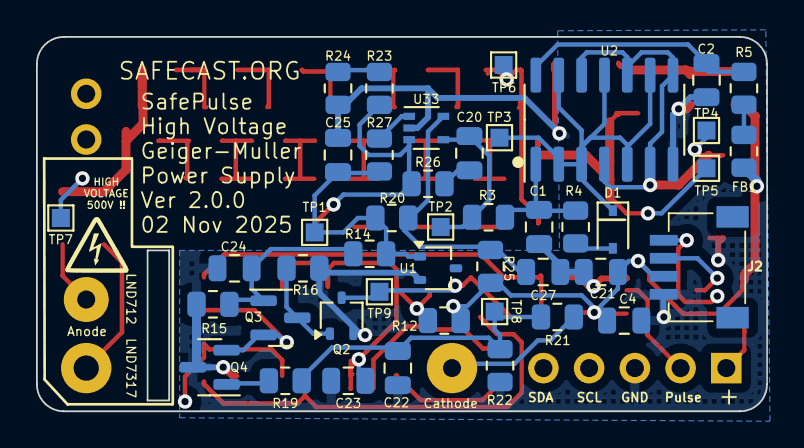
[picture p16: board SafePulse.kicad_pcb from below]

Board: 4 copper layers, 40.6 x 20.8 mm, 92 parts (45 on the bottom side), 51 nets.

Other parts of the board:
G3, G3#2: LOGO; HV warning

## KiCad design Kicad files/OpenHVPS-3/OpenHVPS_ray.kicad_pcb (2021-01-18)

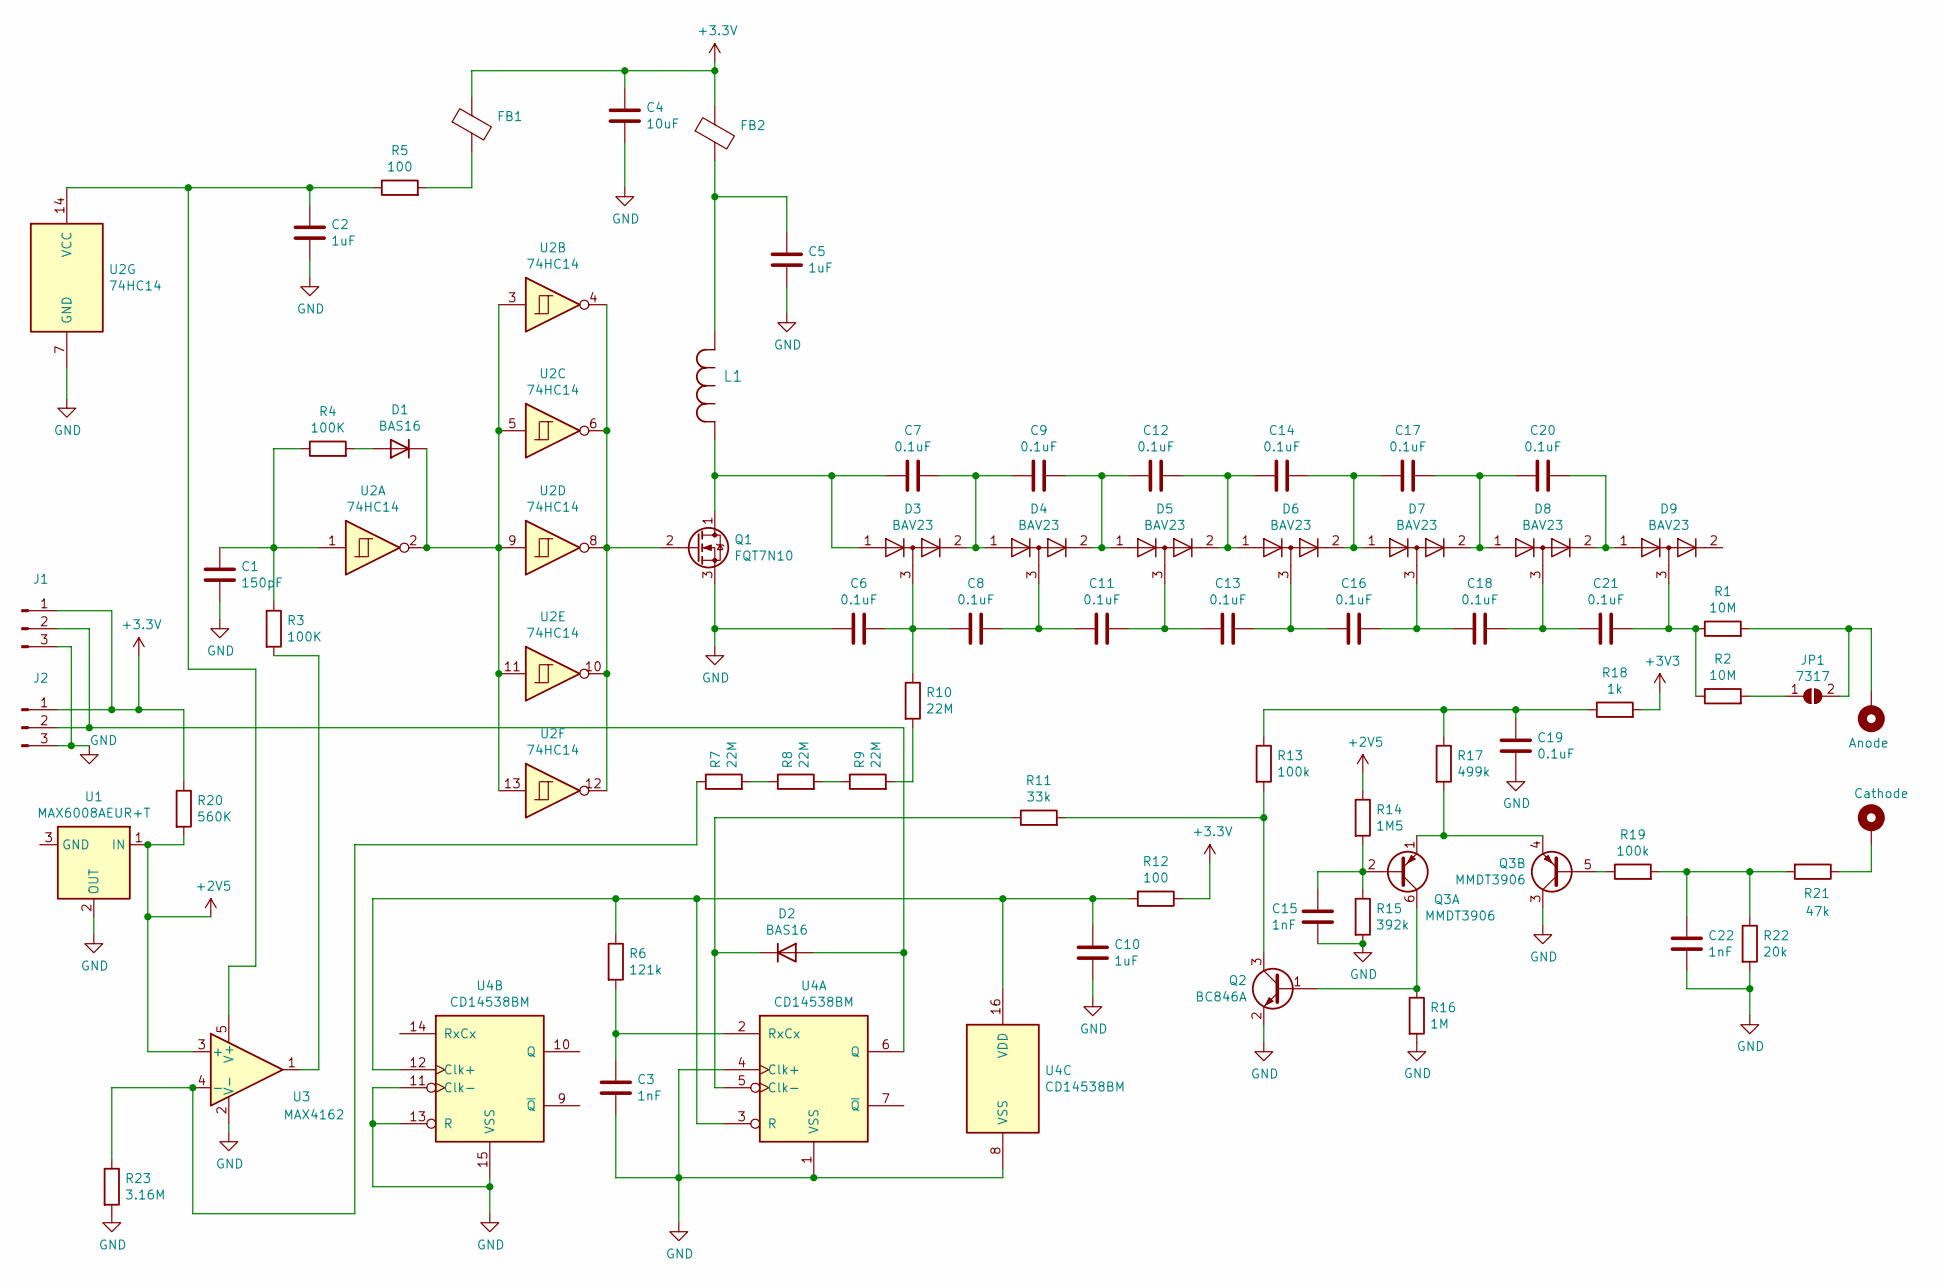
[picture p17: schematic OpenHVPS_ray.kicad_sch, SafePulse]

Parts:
C1: 150pF; C_0805_2012Metric
C2, C5, C10: 1uF; C_0805_2012Metric
C3, C15, C22: 1nF; C_0805_2012Metric
C4: 10uF; C_1210_3225Metric
C6, C7, C8, C9, C11, C12, C13, C14, C16, C17, C18, C19, C20, C21: 0.1uF; C_0805_2012Metric
D1, D2: BAS16; D_SOT-23_ANK
D3, D4, D5, D6, D7, D8, D9: BAV23; SOT-23
FB1, FB2: BKP2125HS221-T; R_0805_2012Metric
H1: Cathode; TestPoint_Loop_D3.80mm_Drill2.0mm
H2: Anode; TestPoint_Loop_D3.80mm_Drill2.0mm
J1, J2: Conn_01x03_Male; PinHeader_1x03_P2.54mm_Vertical
JP1: 7317; SolderJumper-2_P1.3mm_Open_RoundedPad1.0x1.5mm
L1: NRS6020T2R2NMGJ; L_Taiyo-Yuden_MD-4040
Q1: FQT7N10; SOT-223-3_TabPin2
Q2: BC846A; SOT-23
Q3: MMDT3906; SOT-363_SC-70-6
R1, R2: 10M; R_1206_3216Metric
R3, R4: 100K; R_0805_2012Metric
R5, R12: 100; R_0805_2012Metric
R6: 121k; R_0805_2012Metric
R7, R8, R9, R10: 22M; R_0805_2012Metric
R11: 33k; R_0805_2012Metric
R13, R19: 100k; R_0805_2012Metric
R14: 1M5; R_0805_2012Metric
R15: 392k; R_0805_2012Metric
R16: 1M; R_0805_2012Metric
R17: 499k; R_0805_2012Metric
R18: 1k; R_0805_2012Metric
R20: 560K; R_0805_2012Metric
R21: 47k; R_0805_2012Metric
R22: 20k; R_0805_2012Metric
R23: 3.16M; R_0805_2012Metric
U1: MAX6008AEUR+T; SOT-23
U2: 74HC14; SOIC-14_3.9x8.7mm_P1.27mm
U3: MAX4162; SOT-23-5
U4: CD14538BM; SOIC-16_3.9x9.9mm_P1.27mm

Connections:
+2V5: R14.1, R20.2, U1.1 (IN), U3.3 (+)
GND: C1.2, C2.2, C3.2, C4.2, C5.2, C6.1, C10.2, C15.2, C19.2, C22.2, J1.3, J2.3, Q1.3 (S), Q2.2 (E), Q3.3 (C2), R15.2, R16.2, R22.2, R23.2, U1.2 (OUT), U2.7 (GND), U3.2 (V-), U4.1 (VSS), U4.4 (Clk+), U4.8 (VSS), U4.11 (Clk-), U4.13 (R), U4.15 (VSS)
unnamed: C1.1, R3.1, R4.1, U2.1
unnamed: C2.1, R5.1, U2.14 (VCC), U3.5 (V+)
unnamed: C3.1, R6.2, U4.2 (RxCx)
unnamed: C5.1, FB2.2, L1.1
unnamed: C6.2, C8.1, D3.3 (K), R10.1
unnamed: C7.1, D3.1 (K), L1.2, Q1.1 (D)
unnamed: C7.2, C9.1, D3.2 (A), D4.1 (K)
unnamed: C10.1, R6.1, R12.2, U4.3 (R), U4.12 (Clk+), U4.16 (VDD)
unnamed: C8.2, C11.1, D4.3 (K)
unnamed: C11.2, C13.1, D5.3 (K)
unnamed: C9.2, C12.1, D4.2 (A), D5.1 (K)
unnamed: C12.2, C14.1, D5.2 (A), D6.1 (K)
unnamed: C13.2, C16.1, D6.3 (K)
unnamed: C14.2, C17.1, D6.2 (A), D7.1 (K)
unnamed: C15.1, Q3.2 (B1), R14.2, R15.1
unnamed: C16.2, C18.1, D7.3 (K)
unnamed: C17.2, C20.1, D7.2 (A), D8.1 (K)
unnamed: C18.2, C21.1, D8.3 (K)
unnamed: C19.1, R13.1, R17.1, R18.1
unnamed: C20.2, D8.2 (A), D9.1 (K)
unnamed: C21.2, D9.3 (K), R1.1, R2.1
unnamed: C22.1, R19.2, R21.2, R22.1
unnamed: D1.1 (K), U2.2, U2.3, U2.5, U2.9, U2.11, U2.13
unnamed: D1.2 (A), R4.2
unnamed: D2.1 (K), R11.1, U4.5 (Clk-)
unnamed: FB1.2, R5.2
unnamed: H1.1, R21.1
unnamed 29: H2.1, JP1.2 (B), R1.2; also elsewhere on the board
unnamed: D2.2 (A), J1.2, J2.2, U4.6 (Q)
unnamed: JP1.1 (A), R2.2
unnamed: Q1.2 (G), U2.4, U2.6, U2.8, U2.10, U2.12
unnamed: Q2.1 (B), Q3.6 (C1), R16.1
unnamed: Q2.3 (C), R11.2, R13.2
unnamed: Q3.1 (E1), Q3.4 (E2), R17.2
unnamed: Q3.5 (B2), R19.1
unnamed: R3.2, U3.1
unnamed: R7.2, R8.1
unnamed: R8.2, R9.1
unnamed: R9.2, R10.2
unnamed: R7.1, R23.1, U3.4 (-)
no_connect_(D9-Pad2): D9.2 (A)
no_connect_(U1-Pad3): U1.3 (GND)
no_connect_(U4-Pad7): U4.7 (~Q)
no_connect_(U4-Pad9): U4.9 (~Q)
no_connect_(U4-Pad10): U4.10 (Q)
no_connect_(U4-Pad14): U4.14 (RxCx)

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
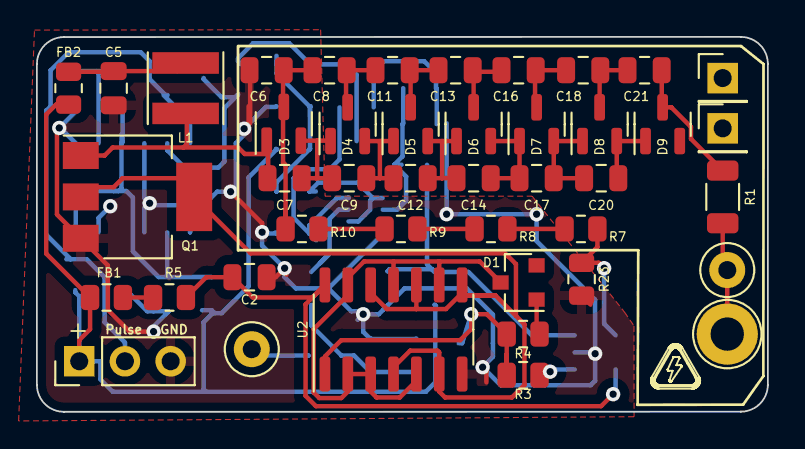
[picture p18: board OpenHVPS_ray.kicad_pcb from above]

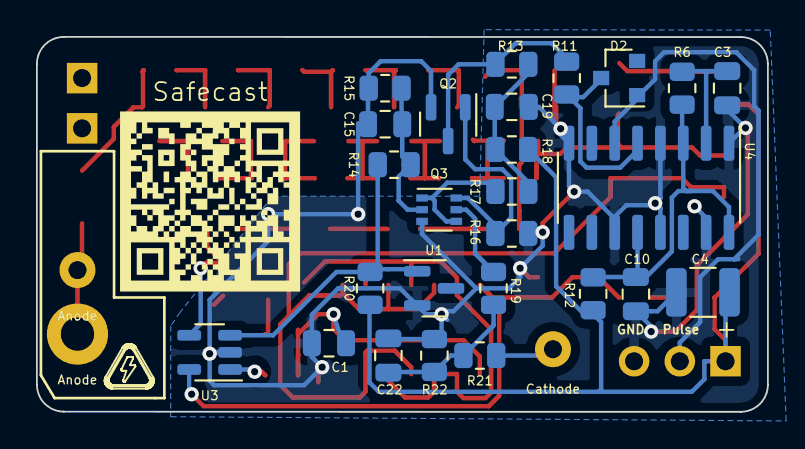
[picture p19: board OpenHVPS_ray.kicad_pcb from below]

Board: 2 copper layers, 40.6 x 20.8 mm, 67 parts (26 on the bottom side), 42 nets.

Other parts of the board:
H2#2: Anode; TestPoint_Loop_D2.50mm_Drill1.85mm

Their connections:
unnamed 29: H2#2.1; also elsewhere on the board

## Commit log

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2021-01-10 Updated with Allan his work.
    [OpenRover.dsn, OpenRover.kicad_pcb, OpenRover.kicad_sch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]
2021-01-10 Tested 74HC14 adding to the footprints
    [OpenRover.dsn, OpenRover.kicad_pcb, OpenRover.kicad_sch]
2021-01-10 Updated test for board sizes
    [OpenRover.dsn, OpenRover.kicad_pcb]
2021-01-11 Updated the files from the allan zip files.
    [OpenRover.kicad_pcb, OpenRover.kicad_sch]
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2021-01-11 quick test parts layout/route and 3d models
    [OpenRover.dsn, OpenRover.kicad_pcb]
2021-01-12 Renamed the files for OpenHVPS
    [OpenHVPS.dsn, OpenHVPS.kicad_pcb, OpenHVPS.kicad_sch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]
2021-01-12 Updated board with fill areas
    [OpenHVPS.kicad_pcb]
2021-01-12 Tested new layout board
    [OpenHVPS.kicad_pcb, OpenRover.dsn]
2021-01-12 Round conners and less vias. Space around holes
    [OpenHVPS.dsn, OpenHVPS.kicad_pcb, OpenRover.dsn]
2021-01-12 version 2 of the SafePulse
    [OpenHVPS-1.dsn, OpenHVPS-1.kicad_pcb, OpenHVPS-1.kicad_sch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]
2021-01-13 Added extra outputs and A-C placement moved
    [OpenHVPS-1.dsn, OpenHVPS-1.kicad_sch, OpenHVPS-11.step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]
2021-01-13 cd \Users\allan\OneDrive\Documents\OpenHVPS Please enter the commit message for your changes. Lines starting updated the long board design
    [OpenHVPS-1.kicad_pcb]
2021-01-13 changes to anode and cathode plus some parts layout, not routed!
    [OpenHVPS-1.kicad_pcb, OpenHVPS-1.kicad_sch]
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2021-01-14 Changed foot prints for Anade/Cathode
    [OpenHVPS-1.kicad_pcb]
2021-01-14 Replaced foot prints of anaode/cathode and text
    [OpenHVPS-1.kicad_pcb, OpenHVPS-11.step, OpenHVPS_1.FCStd]
2021-01-14 moved components around to shorten tracks, trying to keep layout critical stuff together
    Please enter the commit message for your changes. Lines starting
    [OpenHVPS-1.kicad_pcb]
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2021-01-15 Moved components around and routed again.
    [OpenHVPS-2.dsn, OpenHVPS-2.kicad_pcb]
2021-01-15 Moved terminal bloack away from HV
    [OpenHVPS-2.kicad_sch]
2021-01-15 small changes board layout and rerouted
    [OpenHVPS-2.dsn, OpenHVPS-2.kicad_pcb]
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2021-01-16 One more rerout to cleanup.
    [OpenHVPS-2.dsn, OpenHVPS-2.kicad_pcb]
2021-01-17 Sanity checks, parts shuffling, optimize copper pours
    [OpenHVPS-2.kicad_pcb, OpenHVPS-2.kicad_sch]
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2021-01-17 BOM mostly done. cleaned up component labels
    [OpenHVPS-2.kicad_pcb, OpenHVPS-2.kicad_sch]
2021-01-17 Created BOM. updated component markings
    [OpenHVPS-2.kicad_pcb, OpenHVPS-2.kicad_sch]
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2021-01-17 Adjusted text and changde sizes
    [OpenHVPS-2.csv, OpenHVPS-2.kicad_pcb]
2021-01-17 deleting local files to allow pull
    [OpenHVPS-2.kicad_pcb, OpenHVPS-2.kicad_sch]
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2021-01-17 Forgot the supply to the opamp - added. changed a capacitor value
    [OpenHVPS-2.kicad_pcb, OpenHVPS-2.kicad_sch]
2021-01-17 Added space at bottom and routed track +graphic.
    [OpenHVPS-2.dsn, OpenHVPS-2.kicad_pcb]
2021-01-17 Fixed trace too close to Anode. flipped U3 to other side
    [OpenHVPS-2.kicad_pcb]
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2021-01-18 fixed a couple of errors in BOM. reduced size of 2 diodes
    [OpenHVPS_ray.kicad_pcb, OpenHVPS_ray.kicad_sch]
2021-01-18 Added a fuse for reverse polarity protection
    [OpenHVPS_ray.kicad_pcb, OpenHVPS_ray.kicad_sch]
2021-01-18 Flipped R1 and +-P-GND and naming
    [OpenHVPS_ray.FCStd, OpenHVPS_ray.kicad_pcb, OpenHVPS_ray.kicad_sch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]
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2021-01-18 Fixed up
    [OpenHVPS-2.dsn, OpenHVPS-2.kicad_pcb, OpenHVPS-2.kicad_sch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]
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2021-01-19 added latest chnages form Allan
    [OpenHVPS_ray.kicad_pcb, OpenHVPS_ray.kicad_sch]
2021-01-19 Corrected C22 value to 360pF updated BOM
    [OpenHVPS-1.dsn, OpenHVPS-1.kicad_pcb, OpenHVPS-1.kicad_sch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]
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2021-01-19 Updated C22 to 369pF
    [OpenRover-4.kicad_pcb]
2021-01-19 Updated BOM clickable URL BOM
    [OpenHVPS_ray.kicad_pcb, OpenHVPS_ray.kicad_sch, OpenRover-4.csv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]
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2021-01-20 added bom for PCBway and SEEED
    [OpenRover-4-B_Cu.gbl, OpenRover-4-B_Mask.gbs, OpenRover-4-B_Paste.gbp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]
2021-01-20 Changed D1 D2 added F1 and updated BOM
    [OpenRover-4.kicad_pcb, OpenRover-4.kicad_sch]
2021-01-20 Fixed DRC erros in layout, changed final BOM
    [OpenRover-4-B_Cu.gbl, OpenRover-4-B_Mask.gbs, OpenRover-4-B_Paste.gbp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]
2021-01-20 Moved some lables around
    [OpenRover-4.kicad_pcb]
2021-01-21 Some more small adjustment of the graphics.
    [OpenRover-4.kicad_pcb]
2021-01-21 Updated BOM fro SEEED
    [OpenRover-4-B_Cu.gbl, OpenRover-4-B_Mask.gbs, OpenRover-4-B_Paste.gbp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]
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2021-01-23 Update the connectors sizes and two pin header
    [OpenRover-4.kicad_pcb]
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2021-01-23 Fixed bom for Digikey
    [OpenHVPS-4 BOM .xlsx, OpenHVPS-4 BOM for Digikey.xlsx]
2021-01-23 Cleaned up old nameing of the repo
    [OpenHVPS-5-B_Cu.gbl, OpenHVPS-5-B_Mask.gbs, OpenHVPS-5-B_Paste.gbp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]
2021-01-24 Resetted head
    [OpenHVPS-4 BOM .xlsx, OpenHVPS-4 BOM for Digikey.xlsx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]
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2021-02-08 Updated schematic fix Q1 pads
    [OpenHVPS-2.dsn, OpenHVPS-5.kicad_pcb, OpenHVPS-5.kicad_sch]
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2021-02-09 fixed missing graphis and 3d model
    [LND-712-ASSY.stl, OpenHVPS-5.FCStd, OpenHVPS-5.csv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]
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2021-02-10 updated board fixed via's DRC error.
    [OpenHVPS-5.kicad_pcb]
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2021-02-12 Changed Q3 package to single transitor. Now Q3+Q4
    [2021-02-03T060943Dgikey card order.xlsx, BomTemplate.xls, Bom_8539401.csv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]
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2021-02-17 updated text for model to avoid the via.
    [OpenHVPS-5.kicad_pcb, OpenHVPS-5.kicad_sch]
2021-02-17 Updated RC network around opamp and text changes.
    [Digikey Bom_8548835.csv, OpenHVPS-5.csv, OpenHVPS-5.dsn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]
2021-02-17 Updated with TP and some other small changes.
    [OpenHVPS-5.kicad_pcb, OpenHVPS-5.kicad_sch]
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2021-02-21 Moved some lables a bit to get them centered.
    [OpenHVPS-5.dsn, OpenHVPS-5.kicad_pcb]
2021-02-24 added digikey bom from Allan and move U4 label
    [DIGIKEY_safepulse1.1.2.csv, DigiKey Bom_8557668.csv, Digikey Bom_8548835.csv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]
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2021-08-19 Fixed QR logo
    [SafePulse.kicad_pcb]
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2021-08-22 Updated Schematic and Board with new C1 and new R24 values
    [SafePulse.kicad_pcb, SafePulse.kicad_sch]
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2022-03-09 Checked out the files in thelatest version of Kicad Nightly.
    [SafePulse.kicad_pcb, SafePulse.kicad_sch]
2022-05-02 Updated C22 and R22 according to Joseph tests
    [SafePulse.kicad_pcb, SafePulse.kicad_sch]
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2024-07-16 Update layout for SOT-323 for U1 from a SOT-23 footprint
    [SafePulse.kicad_pcb, SafePulse.kicad_sch]
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2025-04-04 Added QR code and updated files from Allan
    [SafePulse.kicad_pcb, SafePulse.kicad_sch, bom.csv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]
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2025-04-05 Aligned labels on board and replaces text labels in schematics
    [SafePulse.kicad_pcb, SafePulse.kicad_sch]
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2025-04-12 V1.2.6 with update BOM and C3 to 1nf
    [SafePulse.kicad_sch, bom.csv]
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2025-11-01 Update V2.0.0 boards and small labels moving around
    [BOM-SafePulse.csv, LND-712-ASSY.stp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]
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2025-11-01 One more fix
    [SafePulse.kicad_pcb]
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2025-11-02 Cleaned up files . JLCPCB production files generated for V2.0.0
    [BOM-SafePulse.csv, LND-712-ASSY.stp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]
